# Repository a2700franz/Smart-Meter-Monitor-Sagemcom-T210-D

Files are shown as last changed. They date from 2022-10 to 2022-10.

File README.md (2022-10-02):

# Smart Meter Monitor
M-Bus Adapter für Smart Meter Sagemcom T210-D der Netz-NOE mit galvanischer Trennung und Übertragung der Daten ins WLAN.

ACHTUNG: Alle hier eingestellten Informationen erfolgen ohne Gewähr. Dies ist keine Nachbauanleitung, sonder beschreibt lediglich wie ich an diese Projekt herangegangen bin.

grafik

Der M-Bus Adapter nutzt die Tatsache, dass das Smart Meter keine Eingaben erfordert. Dadurch genügt die einfache Ansteuerung eines Optokopplers. Die M-Bus Leitungen müssen polrichtig angeschlossen werden. Eine Vertauschung ist unkritisch, ergibt jedoch keine Funktion.

Um ein sauberes Signal sicherzustellen wird ein Schmitt-Trigger benutzt. Die überzähligen Gatter können mittels Jumper für eine Ledanzeige genutzt werden.

Der Optokoppler benötigt eine Stromversorgung zwischen 3V3 und 5V. Der Pegel des Ausgangssignals liegt dann ebenfalls in diesem Bereich.

Der M-Bus Transmitter ist getrennt vom Adapter aufgebaut und dient zur drahtlosen Übertragung der Daten. Es kann hier jeder ESP benutzt werden, die Platine ist für einen ESP-12F ausgelegt, der sich gerade in der Bastelkiste befand. Auf der Platine wurden auch zwei Schalter integriert um sie auch zum Flashen des ESP verwenden zu können.

Die Schalpläne und Platinen wurden mit Eagle gezeichnet.

Die Software für den Transmitter wurde mit der Arduino IDE erstellt. Die Daten werden von der M-Bus Schnittstelle entgegengenommen und mittels UDP an eine beliebige Zieladresse im WLAN weitergeleitet. Wenn kein WLAN gefunden wird startet der der Transmitter als AccessPoint (IP: 192.168.4.1). Die Konfiguration kan dann über ein Webinterface eingestellt werden. Die Software unterstützt OTA und Debugging über UDP.

Die Daten werden bei mir von einem Raspberry 3B zur Decodierung und Aufbereitung entgegengenommen. Ein entsprechendes Python-Programm liegt als Beispiel bei.

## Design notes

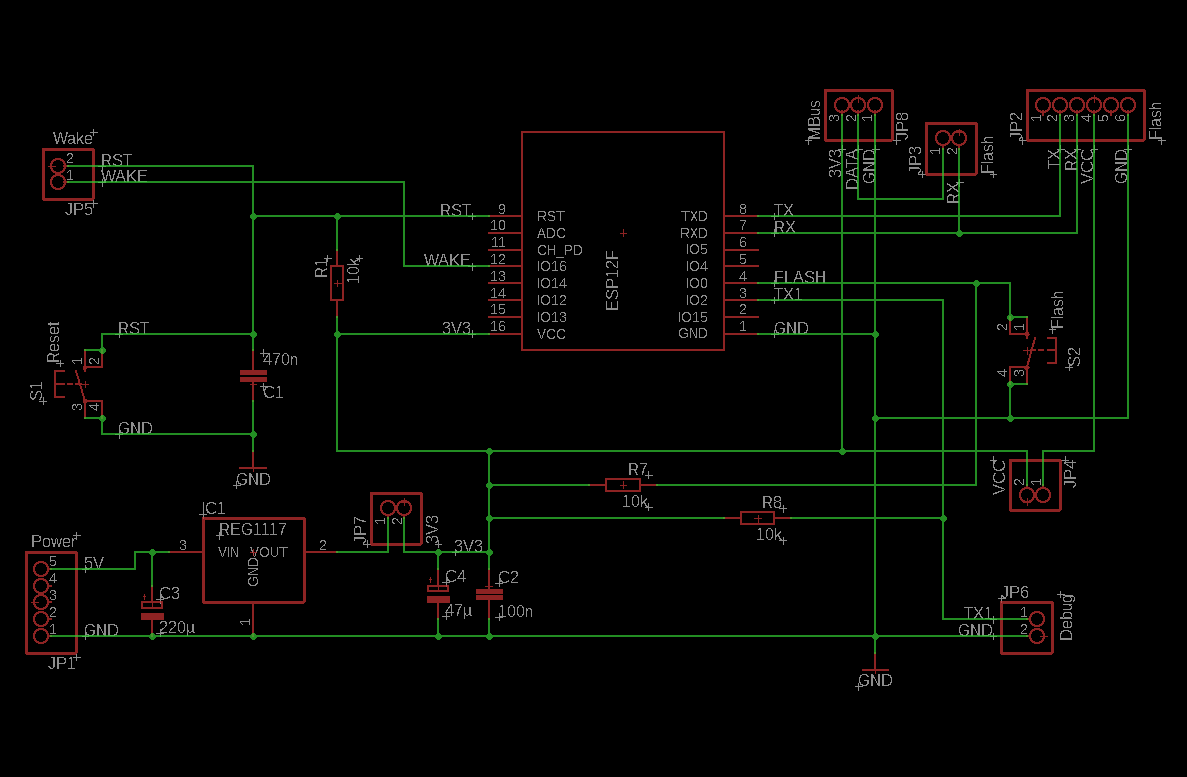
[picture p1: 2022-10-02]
MBusTransmitter.PNG

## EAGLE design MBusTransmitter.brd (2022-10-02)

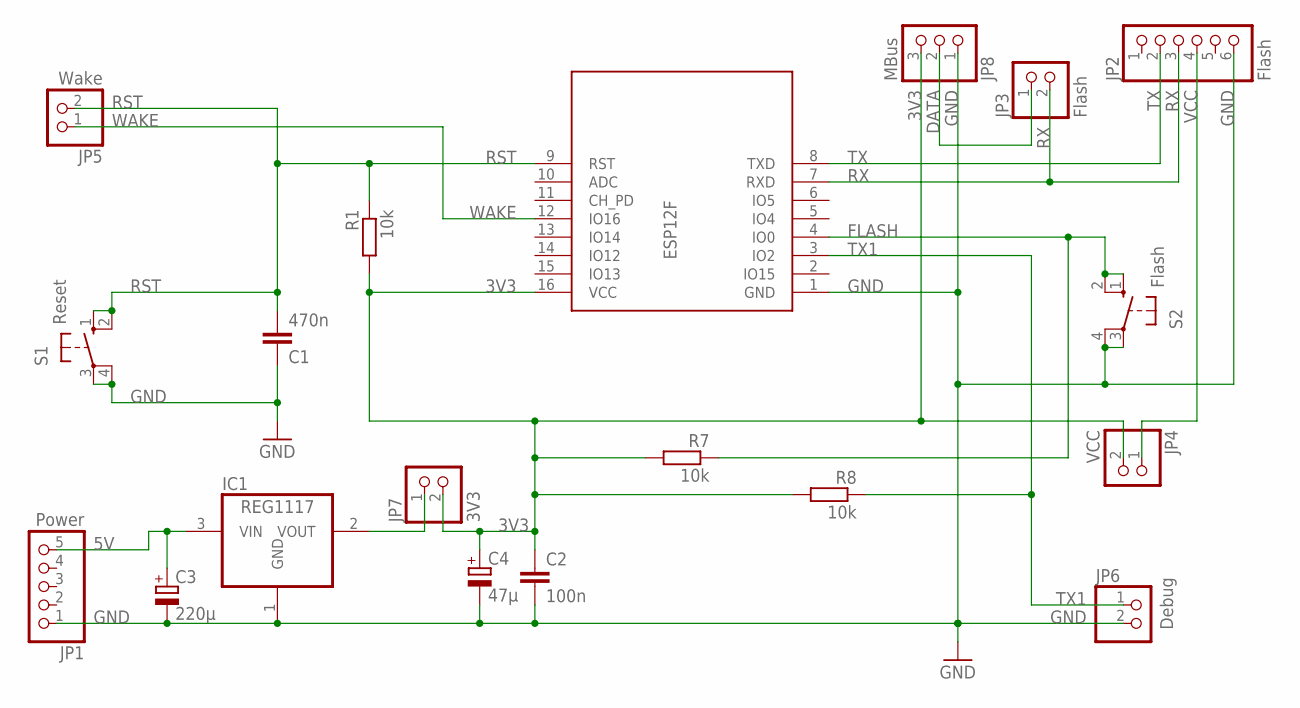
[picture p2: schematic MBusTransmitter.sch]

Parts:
C1: 470n; C050-024X044
C2: 100n; C050-024X044
C3: 220µ; E5-10,5
C4: 47µ; E2,5-5
IC1: REG1117; SOT223
JP1: Power; 1X05
JP2: Flash; 1X06
JP3: Flash; 1X02
JP4: VCC; 1X02
JP5: Wake; 1X02
JP6: Debug; 1X02
JP7: 3V3; 1X02
JP8: MBus; 1X03/90
R1, R7, R8: 10k; 0207/10
S1: Reset; B3F-10XX
S2: Flash; B3F-10XX
U$2: ESP12F

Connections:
3V3: C2.1, C4.+, JP4.2, JP7.2, JP8.3, R1.2, R7.2, R8.2, U$2.16 (VCC)
5V: C3.+, IC1.3 (VIN), JP1.5
DATA: JP3.1, JP8.2
FLASH: R7.1, S2.1 (S), S2.2 (S1), U$2.4 (IO0)
GND: C1.1, C2.2, C3.-, C4.-, IC1.1 (GND), JP1.1, JP2.6, JP6.2, JP8.1, S1.3, S1.4 (P1), S2.3, S2.4 (P1), U$2.1 (GND)
unnamed: IC1.2 (VOUT), JP7.1
RST: C1.2, JP5.2, R1.1, S1.1 (S), S1.2 (S1), U$2.9 (RST)
RX: JP2.3, JP3.2, U$2.7 (RXD)
TX: JP2.2, U$2.8 (TXD)
TX1: JP6.1, R8.1, U$2.3 (IO2)
VCC: JP2.4, JP4.1
WAKE: JP5.1, U$2.12 (IO16)

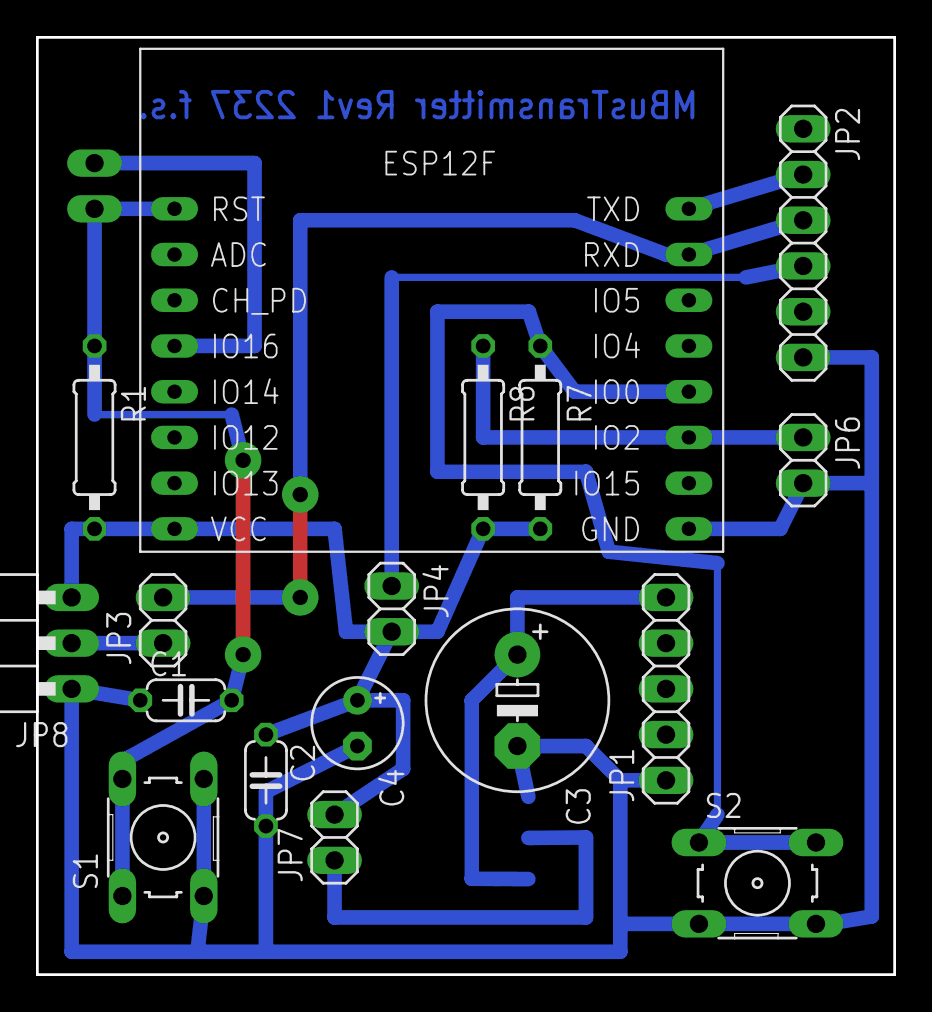
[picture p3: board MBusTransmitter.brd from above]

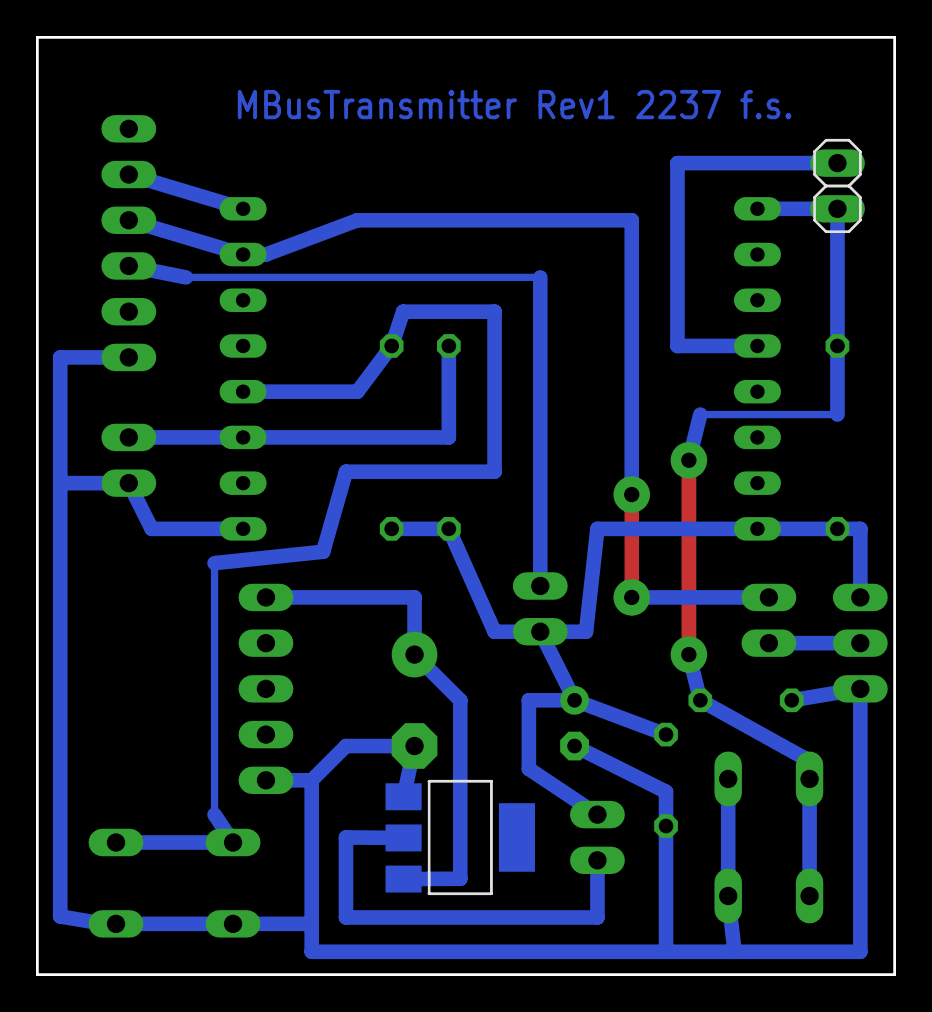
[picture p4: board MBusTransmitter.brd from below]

Board: 2 copper layers, 47.6 x 52.1 mm, 19 parts (2 on the bottom side), 12 nets.

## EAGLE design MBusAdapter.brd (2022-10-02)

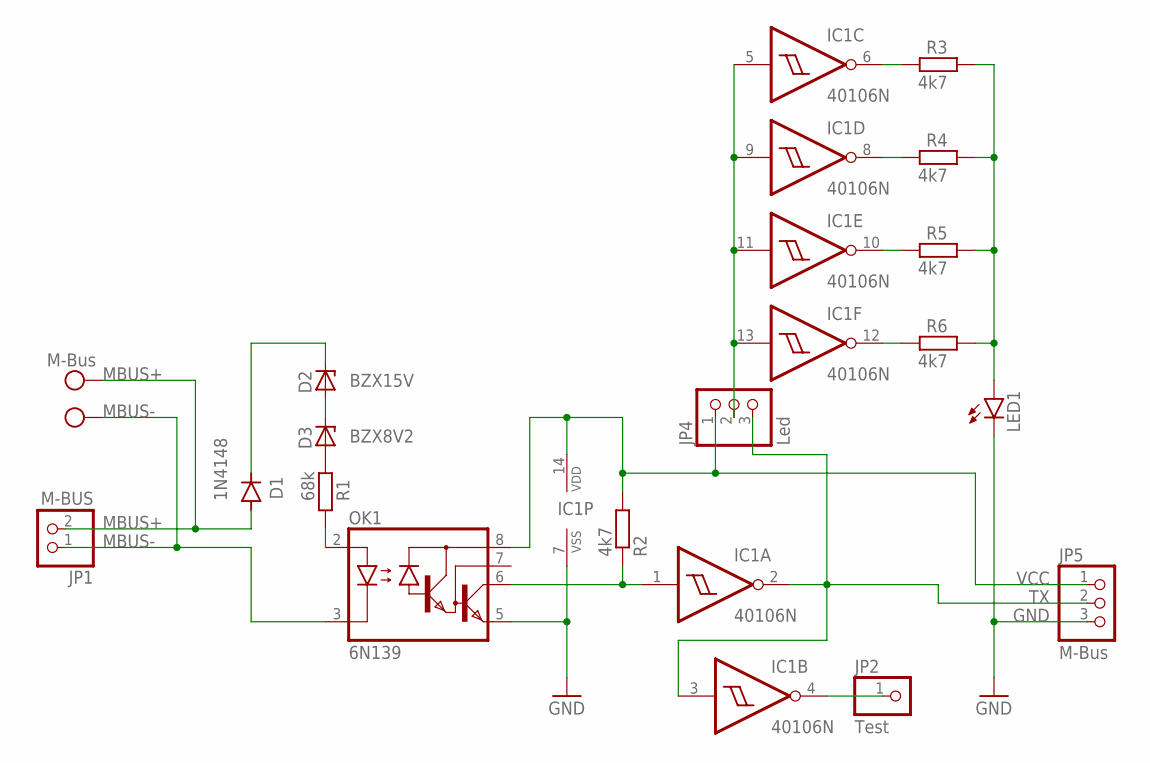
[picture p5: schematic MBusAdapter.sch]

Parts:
D1: 1N4148; DO35-10
D2: BZX15V; DO34Z7
D3: BZX8V2; DO34Z7
IC1: 40106N; DIL14
JP1: M-BUS; 1X02
JP2: Test; 1X01
JP4: Led; 1X03
JP5: M-Bus; 1X03
LED1: TLLG4400; LED3MM
M-BUS: M-Bus; W237-102
OK1: 6N139; DIL08
R1: 68k; 0207/10
R2, R3, R4, R5, R6: 4k7; 0207/10

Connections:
GND: IC1.7 (VSS), JP5.3, LED1.K (C), OK1.5 (GND)
MBUS+: D1.A, JP1.2, M-BUS.2
MBUS-: JP1.1, M-BUS.1, OK1.3 (C)
unnamed: D1.C, D2.C
unnamed: D2.A, D3.C
unnamed: D3.A, R1.2
unnamed: OK1.2 (A), R1.1
unnamed: IC1.6 (O), R3.2
unnamed: IC1.1 (I), OK1.6 (VO), R2.1
unnamed: IC1.8 (O), R4.2
unnamed: IC1.10 (O), R5.2
unnamed: IC1.12 (O), R6.2
unnamed: LED1.A, R3.1, R4.1, R5.1, R6.1
unnamed: IC1.5 (I), IC1.9 (I), IC1.11 (I), IC1.13 (I), JP4.2
unnamed: IC1.4 (O), JP2.1
TX: IC1.2 (O), IC1.3 (I), JP4.3, JP5.2
VCC: IC1.14 (VDD), JP4.1, JP5.1, OK1.8 (VCC), R2.2

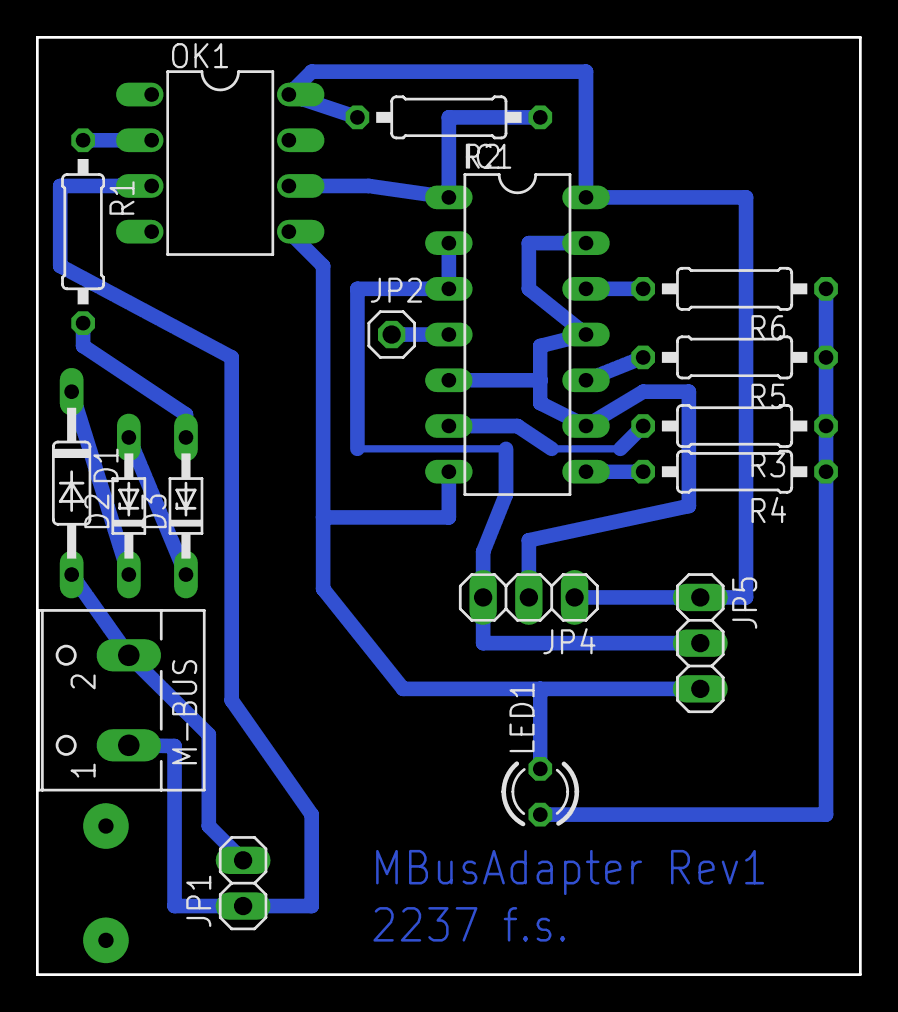
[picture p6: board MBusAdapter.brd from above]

Board: 2 copper layers, 45.7 x 52.1 mm, 17 parts (0 on the bottom side), 17 nets.

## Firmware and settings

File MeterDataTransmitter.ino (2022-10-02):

/*
  M-Bus Data to WLAN transmitter for SmartMeter T210-D
  by Franz Stoiber

  Hints -------------------------------------------------------
  -------------------------------------------------------------

  History -----------------------------------------------------
  2022-09-12 begin programming
  2022-09-21 V1.0
  2022-09-24 web settings for udp and logging included
  2022-09-25 V1.1
  -------------------------------------------------------------

  Bugs --------------------------------------------------------
  -------------------------------------------------------------

  Marks --------------------------------------------------------
  -------------------------------------------------------------

  Hardware ----------------------------------------------------
  controller: ESP8266 80 MHz
  -------------------------------------------------------------

  Pin usage ---------------------------------------------------
  DEV-BOARD                ESP-01
  Pin  5.0V
  Pin  3V3                 VCC 3V3
  Pin  GND                 GND
  Pin  EN                  EN
  Pin  RESET               RST
  Pin  INT
  Pin  MOSI
  Pin  MISO
  Pin  SCLK
  Pin  A0       ADC
  Pin  D0       GPIO16
  Pin  D1/SDA   GPIO5
  Pin  D2/SCL   GPIO4
  Pin  D3       GPIO0      FLASH
  Pin  D4       GPIO2      TX1 (LOG)
  Pin  D5       GPIO14
  Pin  D6       GPIO12
  Pin  D7       GPIO13
  Pin  D8       GPIO15
  Pin  D9       GPIO3      RX0 (DATA)
  Pin  D10      GPIO1      TX0
  -------------------------------------------------------------
*/

//includes
#include <ESP8266WiFi.h>
#include <WiFiClient.h>
#include <WiFiClient.h>
#include <WiFiUdp.h>
#include <ESP8266WebServer.h>
#include <ESP8266mDNS.h>
#include <ESP8266HTTPUpdateServer.h>
#include <EEPROM.h>

//declarations for prg
const String PrgName = "MeterDataTransmitter";
const String PrgVersion = "V1.1";

//declarations for EEPROM
#define EEPROM_Size 256
int32_t EEAdrSsid = 0; //max len 32
int32_t EEAdrPassword = 33;     //max len 63
int32_t EEAdrUDPDataHost = 97;  //max len 15
int32_t EEAdrUDPDataPort = 113; //2 byte
int32_t EEAdrSerialLog = 115;   //1 byte
int32_t EEAdrUDPLog = 116;      //1 byte
int32_t EEAdrUDPLogHost = 117;  //max len 15
int32_t EEAdrUDPLogPort = 133;  //2 byte

//declarations for udp
String UDPDataHost;
IPAddress UDPDataHostIP;
uint16_t UDPDataPort;
String UDPLogHost;
IPAddress UDPLogHostIP;
uint16_t UDPLogPort;

//declarations for logging
uint8_t SerialLog;
uint8_t UDPLog;
char Item[256];

//declarations for WiFi
String Ssid;
String Password;
String APSsid = "MeterDataTransmitter";
String APPassword = "MeterDataTransmitter";
const char* Host = "meter-data-transmitter";
int16_t Rssi;
bool isAP = false;

//declaration for http
String HttpText;

//declarations for frame
const uint16_t FrameLength = 282;

//instance web server
ESP8266WebServer SettingsServer(80);

//instance update server
ESP8266WebServer UpdateServer(81);

//instance web updater
ESP8266HTTPUpdateServer WebUpdater;

//instance WiFiUdp
WiFiUDP udp;

//websites
const String WebHeader = "<html>\
  <head>\
    <title>MeterDataTransmitter</title>\
    <style>\
      body { background-color: #cccccc; font-family: Arial, Helvetica, Sans-Serif; Color: #000088; }\
    </style>\
  </head>";

const String SettingsForm = "<body>\
      <h1>" + PrgName + " " + PrgVersion + "<br>Configuration</h1>\
      #response#\
      <form method=\"post\" enctype=\"application/x-www-form-urlencoded\">\
      SSID:<br>\
      <input type=\"text\" name=\"p_ssid\" value=\"#ssid#\" style=\"width: 300px\"><br><br>\
      Password:<br>\
      <input type=\"text\" name=\"p_pw\" value=\"#password#\" style=\"width: 300px\"><br><br>\
      <br>\
      UDP Data Host IP:<br>\
      <input type=\"text\" name=\"p_dh\" value=\"#udp_data_host#\" style=\"width: 200px\"><br><br>\
      UDP Data Port Nr:<br>\
      <input type=\"text\" name=\"p_dp\" value=\"#udp_data_port#\" style=\"width: 100px\"><br><br>\
      <br>\
      Serial Logging (0/1):<br>\
      <input type=\"text\" name=\"p_ls\" value=\"#serial_log#\" style=\"width: 50\"><br><br>\
      <br>\
      UDP Logging (0/1):<br>\
      <input type=\"text\" name=\"p_lu\" value=\"#udp_log#\" style=\"width: 50\"><br><br>\
      UDP Log Host IP:<br>\
      <input type=\"text\" name=\"p_lh\" value=\"#udp_log_host#\" style=\"width: 200px\"><br><br>\
      UDP Log Port Nr:<br>\
      <input type=\"text\" name=\"p_lp\" value=\"#udp_log_port#\" style=\"width: 100px\"><br><br>\
      <br><br><br>\
      <input type=\"submit\" name=\"p_config\" value=\"store Configuration\" style=\"width: 200px; height:40px;font-weight:bold;font-size:16px\"><br><br>\
    </form>\
    </body>\
  </html>";

const String InfoForm = "<body>\
    <h1>" + PrgName + "</h1>\
    <h4>\
    SSID: #ssid#<br>\
    Password: #password#<br>\
    <br>\
    UDP Data Host: #udp_data_host#<br>\
    UDP Data Port: #udp_data_port#<br>\
    <br>\
    Serial Logging: #serial_log#<br>\
    <br>\
    UDP Logging: #udp_log#<br>\
    UDP Log Host: #udp_log_host#<br>\
    UDP Log Port: #udp_log_port#<br>\
    <br>\
    <br>\
    Configuration stored<br>\
    MeterDataTransmitter restart with new configuration in 10 seconds ...\
    </h4>\
    </body>\
  </html>";

void readConfig() {
  Ssid = EEReadString(EEAdrSsid);
  if (Ssid == "") {
    Ssid = "ssid";
    Password = "password";
  }
  else Password = EEReadString(EEAdrPassword);
  UDPDataHost = EEReadString(EEAdrUDPDataHost);
  if (UDPDataHost == "") UDPDataHost = "192.168.0.000";
  UDPDataHostIP.fromString(UDPDataHost);
  UDPDataPort = EEReadUint16(EEAdrUDPDataPort);
  if (UDPDataPort == 0xffff) UDPDataPort = 5000;
  SerialLog = EEReadUint8(EEAdrSerialLog);
  if (SerialLog != 0) SerialLog = 1;
  UDPLog = EEReadUint8(EEAdrUDPLog);
  if (UDPLog != 0) UDPLog = 1;
  UDPLogHost = EEReadString(EEAdrUDPLogHost);
  if (UDPLogHost == "") UDPLogHost = "192.168.0.000";
  UDPLogHostIP.fromString(UDPLogHost);
  UDPLogPort = EEReadUint16(EEAdrUDPLogPort);
  if (UDPLogPort == 0xffff) UDPLogPort = 5001;
}

void writeConfig() {
  if (Ssid.length() > 32) Ssid = Ssid.substring(0, 32);
  EEWriteString(EEAdrSsid, Ssid);
  EEWriteString(EEAdrPassword, Password);
  EEWriteString(EEAdrUDPDataHost, UDPDataHost);
  EEWriteUint16(EEAdrUDPDataPort, UDPDataPort);
  EEWriteUint8(EEAdrSerialLog, SerialLog);
  EEWriteUint8(EEAdrUDPLog, UDPLog);
  EEWriteString(EEAdrUDPLogHost, UDPLogHost);
  EEWriteUint16(EEAdrUDPLogPort, UDPLogPort);
  EEPROM.commit();
}

String EEReadString(uint16_t EEAdr) {
  uint16_t i;
  uint8_t Len;
  String Text = "";
  Len = EEPROM.read(EEAdr);
  if (Len == 0 || Len == 255) return "";
  EEAdr++;
  for (i = 0; i < Len; i++) Text += char(EEPROM.read(EEAdr + i));
  return Text;
}

void EEWriteString(uint16_t EEAdr, String Text) {
  uint16_t i;
  uint8_t Len;
  Len = Text.length();
  EEPROM.write(EEAdr, Len);
  EEAdr++;
  for (i = 0; i < Len; i++) EEPROM.write(EEAdr + i, Text[i]);
}

uint16_t EEReadUint16(uint16_t EEAdr) {
  uint8_t HiByte;
  uint8_t LoByte;
  HiByte = EEPROM.read(EEAdr);
  LoByte = EEPROM.read(EEAdr + 1);
  return HiByte * 256 + LoByte;
}

void EEWriteUint16(uint16_t EEAdr, uint16_t Value) {
  EEPROM.write(EEAdr, highByte(Value));
  EEPROM.write(EEAdr + 1, lowByte(Value));
}

uint16_t EEReadUint8(uint16_t EEAdr) {
  return EEPROM.read(EEAdr);
}

void EEWriteUint8(uint16_t EEAdr, uint8_t Value) {
  EEPROM.write(EEAdr, Value);
}

void sendUdpData(byte Frame[], uint16_t Len) {
  uint32_t FrameCnt = 0;
  if (connectWiFi(Ssid, Password)) {
    udp.beginPacket(UDPDataHostIP, UDPDataPort);
    udp.write(Frame, Len);
    udp.endPacket();
    FrameCnt = Frame[22] << 24 | Frame[23] << 16 | Frame[24] << 8 | Frame[25];
    Log("data frame " + String(FrameCnt) + " sent\n");
  }
}

void Log(String Message) {
  if (SerialLog != 0) Serial1.print(Message);
  if (UDPLog != 0) {
    if (connectWiFi(Ssid, Password)) {
      udp.beginPacket(UDPLogHostIP, UDPLogPort);
      udp.print(Message);
      udp.endPacket();
    }
  }
}

bool connectWiFi(String Ssid, String Password) {
  uint8_t Attampt = 0;
  if (WiFi.status() != WL_CONNECTED) {
    Serial1.printf("connecting % s ", Ssid);
    WiFi.mode(WIFI_STA);
    WiFi.begin(Ssid, Password);
    while (true) {
      if (WiFi.status() == WL_CONNECTED) break;
      else {
        Attampt += 1;
        Serial1.print(".");
        if (Attampt >= 15) break;
        delay(500);
      }
    }
    Serial1.println();
    if (WiFi.status() == WL_CONNECTED) {
      Log("connected, IP ");
      Log(WiFi.localIP().toString());
      Rssi = WiFi.RSSI();
      sprintf(Item, ", RSSI % d dB\n", Rssi);
      Log(String(Item));
      return true;
    }
    else {
      Serial1.printf("connecting % s failed", Ssid);
      Serial1.print(", status ");
      Serial1.println(WiFi.status() + "");
      return false;
    }
  }
  else return true;
}

void handleWebRequest() {
  String Response;
  if (SettingsServer.args() == 10) {
    //store configuration pressed
    Ssid = SettingsServer.arg(0);
    Password = SettingsServer.arg(1);
    UDPDataHost = SettingsServer.arg(2);
    UDPDataPort = SettingsServer.arg(3).toInt();
    SerialLog = SettingsServer.arg(4).toInt();
    UDPLog = SettingsServer.arg(5).toInt();
    UDPLogHost = SettingsServer.arg(6);
    UDPLogPort = SettingsServer.arg(7).toInt();
    Response = "";
    if (Ssid.length() == 0 || Ssid.length() > 32) Response = "SSID invalid";
    else if (Password.length() < 8 || Password.length() > 63) Response = "Password invalid";
    else if (!UDPDataHostIP.fromString(UDPDataHost)) Response = "UDPDataHost IP invalid";
    else if (!UDPLogHostIP.fromString(UDPLogHost)) Response = "UDPLogHost IP invalid";
    else {
      //send configutation info
      HttpText = WebHeader + InfoForm;
      replaceHttpText();
      SettingsServer.send(200, "text / html", HttpText);
      yield();
      writeConfig();
      Log("ESP8266 restart in 10 sec ...\n");
      delay(10000);
      ESP.restart();
    }
  }
  //send  configuration form
  HttpText = WebHeader + SettingsForm;
  if (Response == "") HttpText.replace("#response#", "");
  else HttpText.replace("#response#", "<font color=\"red\"><b>" + Response + "</b></font><br><br>");
  replaceHttpText();
  SettingsServer.send(200, "text/html", HttpText);
}

void replaceHttpText() {
  HttpText.replace("#ssid#", Ssid);
  HttpText.replace("#password#", Password);
  HttpText.replace("#udp_data_host#", UDPDataHost);
  HttpText.replace("#udp_data_port#", String(UDPDataPort));
  HttpText.replace("#serial_log#", String(SerialLog));
  HttpText.replace("#udp_log#", String(UDPLog));
  HttpText.replace("#udp_log_host#", UDPLogHost);
  HttpText.replace("#udp_log_port#", String(UDPLogPort));
}

void setup(void) {
  //init serial connections
  Serial.begin(2400, SERIAL_8E1);
  Serial1.begin(115200);
  delay(300);

  //print prg infos
  Serial1.println();
  Serial1.print(PrgName);
  Serial1.print("  ");
  Serial1.println(PrgVersion);

  //read configuration
  EEPROM.begin(EEPROM_Size);
  readConfig();

  //init WiFi
  if (connectWiFi(Ssid, Password)) isAP = false;
  else {
    //start access point
    Serial1.println("starting access point ...");
    WiFi.disconnect();
    WiFi.mode(WIFI_AP);
    WiFi.softAP(APSsid, APPassword);
    Serial1.print("access point '");
    Serial1.print(APSsid);
    Serial1.println("' started (" + WiFi.softAPIP().toString() + ")");
    isAP = true;
  }
  //start settings server
  Serial1.println("starting web settings server ...");
  SettingsServer.begin();
  SettingsServer.on("/", handleWebRequest);
  sprintf(Item, "web settings server running (http://%s.local/)\n", Host);
  Log(String(Item));

  //no more actions in ap mode
  if (isAP) return;

  //start update server
  Log("starting web update server ...\n");
  MDNS.begin(Host);
  WebUpdater.setup(&UpdateServer);
  UpdateServer.begin();
  MDNS.addService("http", "tcp", 80);
  sprintf(Item, "web update server running (http://%s.local:81/update)\n", Host);
  Log(String(Item));
}

void loop(void) {
  uint8_t Frame[FrameLength];
  uint16_t i;
  const uint32_t TimeoutMillis = 100;
  uint32_t LastReceiveMillis;

  //handle web request for settings
  SettingsServer.handleClient();

  //no more actions in ap mode
  if (isAP) return;

  //handle web update
  UpdateServer.handleClient();
  MDNS.update();

  //if 282 bytes from m-bus comesin, send it over udp
  if (Serial.available()) {
    LastReceiveMillis = millis();
    i = 0;
    while (true) {
      if (Serial.available()) {
        Frame[i] = Serial.read();
        i += 1;
        LastReceiveMillis = millis();
      }
      if (millis() - LastReceiveMillis >= TimeoutMillis) {
        //reached end of frame
        if (i == FrameLength) sendUdpData(Frame, FrameLength);
        break;
      }
    }
  }

  //reduce power
  delay(1);
}
